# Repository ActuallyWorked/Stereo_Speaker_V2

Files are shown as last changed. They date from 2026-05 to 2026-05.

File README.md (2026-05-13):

# Stereo_Speaker_V2
ECE5 extra credit assignment tasked students with designing a PCB from a provided mono-amplifier schematic. This is an extended version with the following modifications:

Converted the mono circuit into stereo, added a band-pass filter (80Hz-16kHz), 9V regulator, LED power indicator, and integrated with a 100W USB-C PD module from Aliexpress to allow for 100W charging/discharging for mobile devices if needed.

Reasoning: 

Band-pass filter was used to compensate for the extra-long audio cable

9V regulator was used to allow for other power sources besides the in-class 9V alkaline battery -- allowed for Li-ion battery pack to be used and for the use of the 100W USB-C module)

LED power indicator was used to reduce power loss on the LDO and was a nice-to-have feature

100W USB-C module was added because I wanted a battery bank, and I realized I could make a speaker and portable battery at the same time.

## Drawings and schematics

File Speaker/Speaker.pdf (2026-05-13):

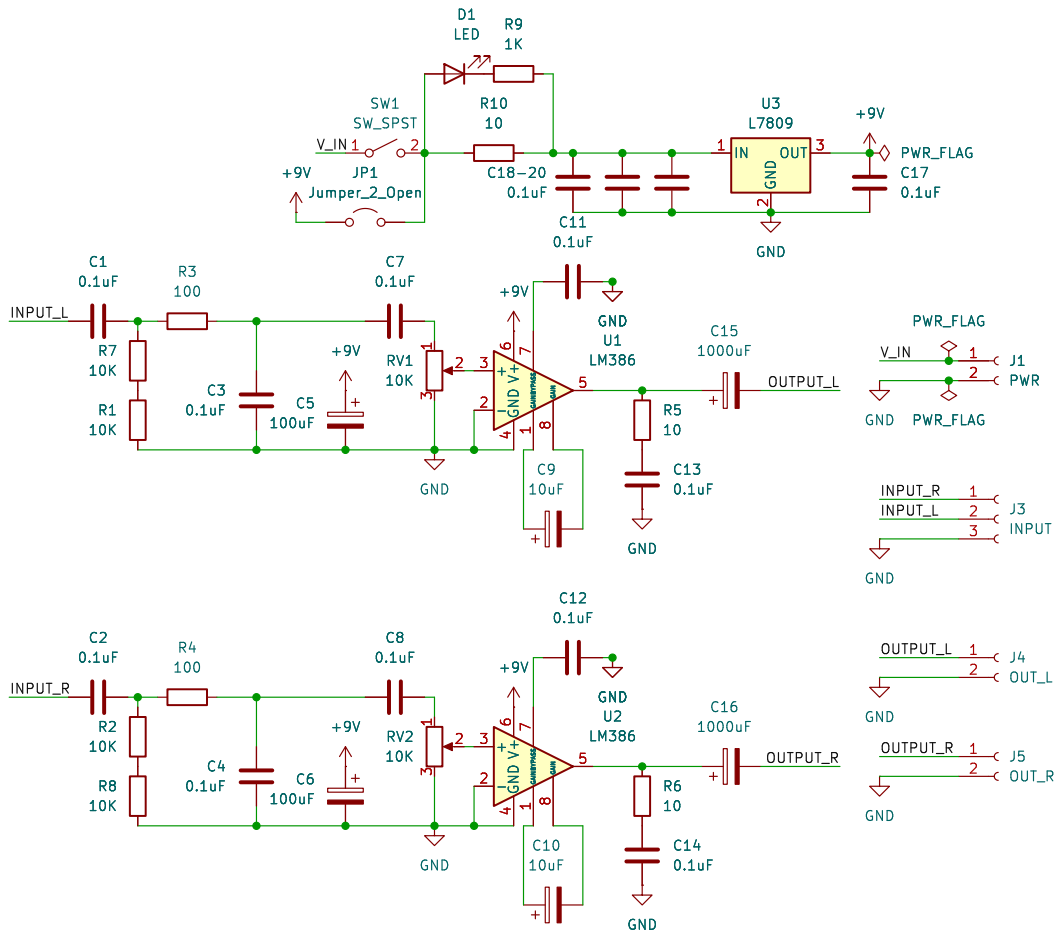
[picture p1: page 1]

File: Speaker.kicad_sch Sheet: / UCSD

Id: 1/1 Title: STEREO SPEAKER FILTER+AMP

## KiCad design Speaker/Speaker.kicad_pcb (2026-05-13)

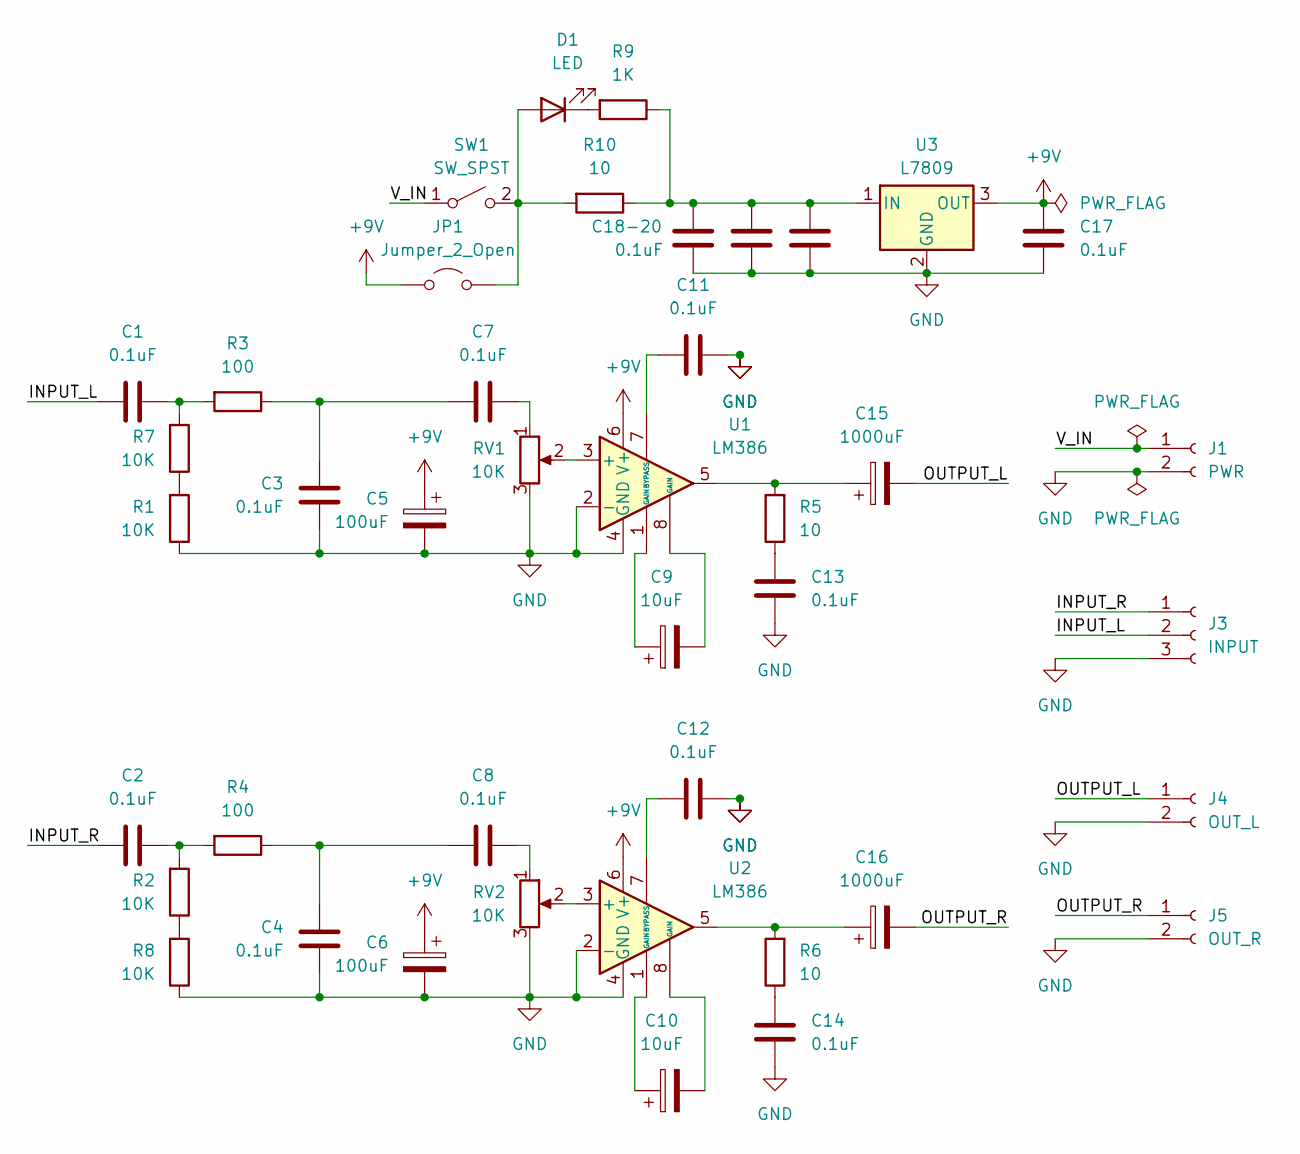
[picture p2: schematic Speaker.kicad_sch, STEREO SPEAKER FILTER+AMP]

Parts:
C1, C2, C3, C4, C7, C8, C11, C12, C13, C14, C17, C18-20, C19, C20: 0.1uF; C_Disc_D3.0mm_W1.6mm_P2.50mm
C5, C6: 100uF; CP_Radial_D8.0mm_P2.50mm
C9, C10: 10uF; CP_Radial_D10.0mm_P5.00mm
C15, C16: 1000uF; CP_Radial_D10.0mm_P5.00mm
D1: LED; LED_D5.0mm
J1: PWR; PinSocket_1x02_P2.54mm_Vertical
J3: INPUT; PinSocket_1x03_P2.54mm_Vertical
J4: OUT_L; PinSocket_1x02_P2.54mm_Vertical
J5: OUT_R; PinSocket_1x02_P2.54mm_Vertical
JP1: Jumper_2_Open; SolderJumper-2_P1.3mm_Open_TrianglePad1.0x1.5mm
R1, R2, R7, R8: 10K; R_Axial_DIN0207_L6.3mm_D2.5mm_P10.16mm_Horizontal
R3, R4: 100; R_Axial_DIN0207_L6.3mm_D2.5mm_P10.16mm_Horizontal
R5, R6, R10: 10; R_Axial_DIN0207_L6.3mm_D2.5mm_P10.16mm_Horizontal
R9: 1K; R_Axial_DIN0207_L6.3mm_D2.5mm_P10.16mm_Horizontal
RV1, RV2: 10K; Potentiometer_Bourns_3386C_Horizontal
SW1: SW_SPST; PinSocket_1x02_P2.54mm_Vertical
U1, U2: LM386; DIP-8_W7.62mm
U3: L7809; TO-220-3_Vertical

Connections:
+9V: C5.1, C6.1, C17.1, JP1.1 (A), U1.6 (V+), U2.6 (V+), U3.3 (OUT); also elsewhere on the board
/INPUT_L: C1.2, J3.2
/INPUT_R: C2.2, J3.1
/OUTPUT_L: C15.2, J4.1
/OUTPUT_R: C16.2, J5.1
/V_IN: J1.1, SW1.1 (A)
GND: C3.2, C4.2, C5.2, C6.2, C11.2, C12.2, C13.1, C14.1, C17.2, C18-20.2, C19.2, C20.2, J1.2, J3.3, J4.2, J5.2, R1.1, R8.1, RV1.3, RV2.3, U1.2 (-), U1.4 (GND), U2.2 (-), U2.4 (GND), U3.2 (GND); also elsewhere on the board
unnamed: C1.1, R3.2, R7.2
unnamed: C2.1, R2.2, R4.2
unnamed: C3.1, C7.2, R3.1
unnamed: C4.1, C8.2, R4.1
unnamed: C7.1, RV1.1
unnamed: C8.1, RV2.1
unnamed: C9.1, U1.1 (GAIN)
unnamed: C9.2, U1.8 (GAIN)
unnamed: C10.1, U2.1 (GAIN)
unnamed: C10.2, U2.8 (GAIN)
unnamed: C13.2, R5.1
unnamed: C14.2, R6.1
unnamed: C15.1, R5.2, U1.5
unnamed: C16.1, R6.2, U2.5
unnamed 21: D1.2 (A), JP1.2 (B), R10.2, SW1.2 (B); also elsewhere on the board
unnamed: D1.1 (K), R9.2
unnamed: R1.2, R7.1
unnamed: R2.1, R8.2
unnamed: RV1.2, U1.3 (+)
unnamed: C11.1, U1.7 (BYPASS)
unnamed: RV2.2, U2.3 (+)
unnamed: C12.1, U2.7 (BYPASS)
unnamed 29: C18-20.1, C19.1, C20.1, R9.1, R10.1, U3.1 (IN); also elsewhere on the board

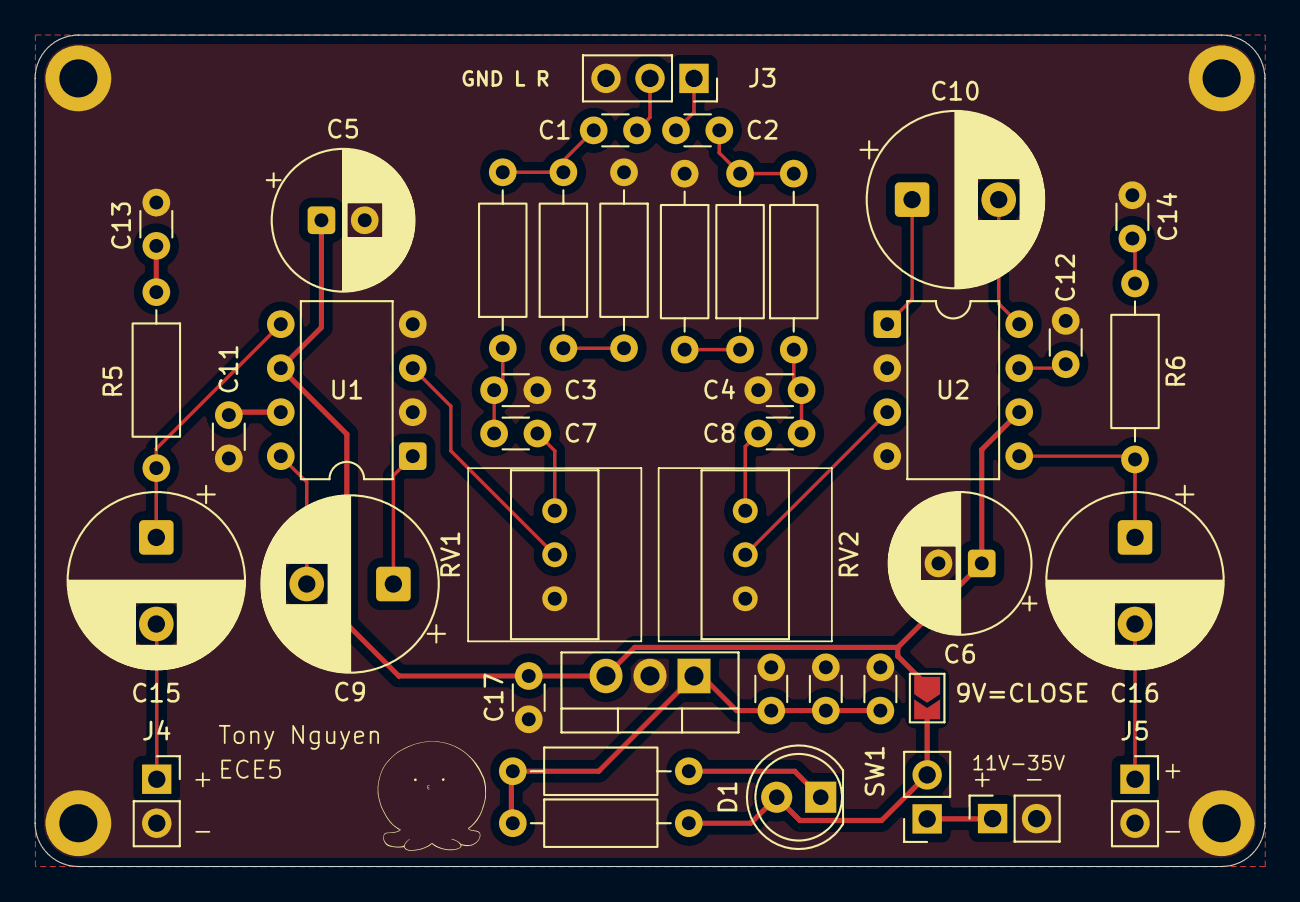
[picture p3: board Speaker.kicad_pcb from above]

Board: 2 copper layers, 71.0 x 48.0 mm, 42 parts (0 on the bottom side), 30 nets.

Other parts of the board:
9V=CLOSE: Jumper_2_Open; SolderJumper-2_P1.3mm_Open_TrianglePad1.0x1.5mm
C18: 0.1uF; C_Disc_D3.0mm_W1.6mm_P2.50mm

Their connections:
+9V: 9V=CLOSE.1 (A); also elsewhere on the board
GND: C18.2; also elsewhere on the board
unnamed 21: 9V=CLOSE.2 (B); also elsewhere on the board
unnamed 29: C18.1; also elsewhere on the board
